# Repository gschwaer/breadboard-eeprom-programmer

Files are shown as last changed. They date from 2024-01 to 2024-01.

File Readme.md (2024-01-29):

# Breadboard EEPROM Programmer

> A parallel EEPROM programmer built on a breadboard.

The **SN74LV8153** is a serial-to-parallel IC. It can translate serial (yes, UART) to 8 parallel
output pins. In combination with a USB-to-serial converter this is a very powerful, yet simple setup
to interact with breadboard circuitry from a computer. We're going to leverage that for building an
EEPROM programmer.

No soldering required. No building firmware. No micro controller. Just assemble the circuit on a
breadboard, connect USB, and you're good to go!

## Hardware

We use three individually addressable SN74LV8153 chips. The one on the left (address 1) is used for
the 7 upper address lines (green) and the write enable signal (white). The one on the right
(address 0) is used for the 8 lower address lines (green). The last one (address 2) is used for the
8 data lines (blue). The serial data line (yellow) connects the TX output of the USB-to-serial
adapter (left) to the RX input of all SN74LV8153. And that's it. Plug the EEPROM in the middle and
get to flashing.

breadboard schematic

Color Coding:
- 🔴 5V
- ⚫ GND
- 🟢 Address Lines
- 🔵 Data Lines
- ⚪ IC Control
- 🟡 Serial

Here is the finished breadboard:

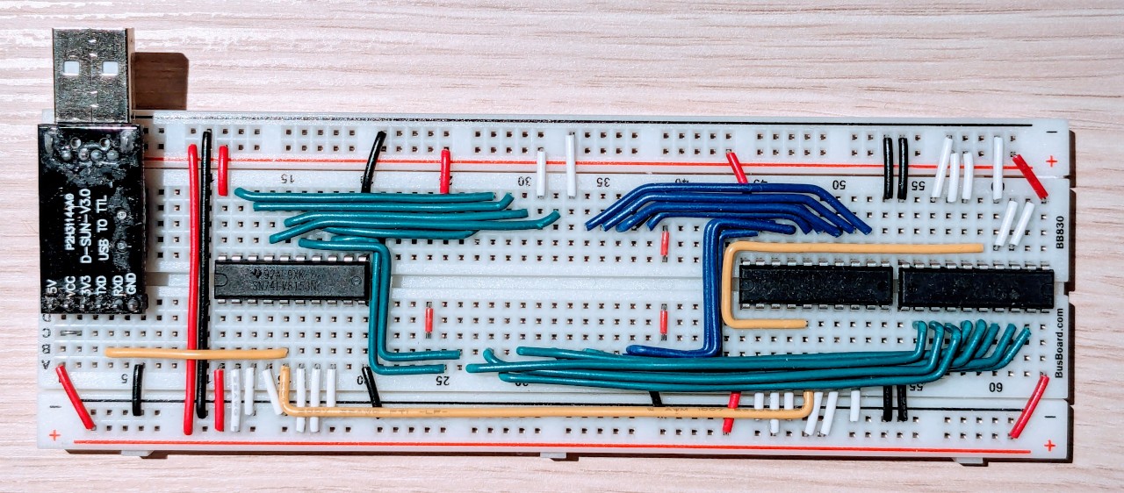
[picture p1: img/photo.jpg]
photo of breadboard


## Software

Written in python using `pyserial`. [Source Code.](bbeeprog.py)

### Setup

```bash
git clone https://github.com/gschwaer/breadboard-eeprom-programmer.git
cd breadboard-eeprom-programmer
python3.9 -m venv .venv
source .venv/bin/activate
pip install --upgrade pip wheel
pip install -r requirements.txt
```
Note: Should work fine with all python versions >= 3.8.

### Usage

Initialize the programmer (do this before inserting the EEPROM!)
```bash
./bbeeprog.py init /dev/ttyUSB0
```

Flash data to the EEPROM
```bash
./bbeeprog.py flash /dev/ttyUSB0 ~/my_file.hex
```

Flash only the data that changed between `~/my_old_file.hex` and `~/my_new_file.hex` to the EEPROM
```bash
./bbeeprog.py flash /dev/ttyUSB0 --only-changes=~/my_old_file.hex ~/my_new_file.hex
```
Warning: Beware, if the provided "old" file is not identical to the content of the EEPROM, the
         result is undefined.

The `--only-changes` option is especially useful when combined with a build script or a Makefile.
The flashing target can copy the binary to a hidden file after flashing and then provide the last
flashed binary on every new flashing. Something like so:
```Makefile
.PHONY: flash
flash: out.hex
ifeq ($(wildcard ./.out.hex),)
	$(bbeeprog) flash $(device) $<
else
	$(bbeeprog) flash --only-changes=.out.hex $(device) $<
endif
	cp out.hex .out.hex
```

## Pros And Cons

The Pros:

- 🧑‍🏭 No soldering needed
  - Circuit works purely on breadboard!
- 💻 No need to build firmware or flash a micro controller
  - It's basically hardware bit-banging with USB as data source!
- 🛒 Low cost
  - 7.62 € for 3x SN74LV8153 (each 2.54 € at Mouser in Jan 2024), the rest is components that you
    probably have laying around (Breadboard, USB-to-serial, and some jumper wires)!
- ✨ Flexible
  - So much possibilities! Some ideas: Need more address lines? Slap another SN74LV8153 on the
    breadboard. Want accurate timing? Trigger a 555 timer. Really want data back? Operate a USART
    like the Intel 8251 via a SN74LV8153.
- ♻️ No waste
  - Don't need it anymore? Disassemble and reuse the parts for some other project!

The Cons:
- 🙉 No input capabilities
  - We cannot read back the EEPROM content, so we cannot validate it either.
- ✋ Not suited for all EEPROMs
  - Built for AT28C256. Others: write cycle timing cannot be too demanding
    ([more](#more-on-limitations)).
- 🔨 Increased memory wear
  - Because of timing restraints, we cannot use the better page-write mode
    ([more](#more-on-limitations)).
- 🐌 Slow
  - Not blazingly fast, but usable for smaller EEPROMs. 32kB works fine.

## Docs

- [SN74LV8153](https://www.ti.com/lit/ds/symlink/sn74lv8153.pdf?ts=1706468538401) -
  Serial-to-parallel data converter
- [AT28C256](https://ww1.microchip.com/downloads/aemDocuments/documents/MPD/ProductDocuments/DataSheets/AT28C256-Industrial-Grade-256-Kbit-Paged-Parallel-EEPROM-Data-Sheet-DS2000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) - 32kB paged
  parallel EEPROM

## More On Limitations

**Timing:** This tool was written for the AT28C256. Others EEPROMs might work as well if they have
lax timing requirements similar to the AT28C256: Other EEPROMS sometimes require a maximum duration
for toggling of the write enable line. The AT28C256 does not have that for byte-wise writing. We
cannot accomplish tight upper bounded timing requirements, because serial via USB is just too slow
and has too much jitter.

**Wear:** We can only use byte-wise writing, because page-wise writing requires accurate timing on
the AT28C256. Instead, writing a page (64 bytes) is done by 64 single writes, that is 64 write
cycles, whereas page-wise writing would need only one cycle for 64 byte. Compared to a programmer
that supports page-wise writing, flashing the same amount of data is much slower and has increased
memory wear (more write cycles). Still, with the AT28C256's listed endurance, we can flash it over
150 times.

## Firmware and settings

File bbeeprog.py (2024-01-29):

"""
Program EEPROM with provided binary data.

Usage: bbeeprog.py init DEVICE
       bbeeprog.py flash [--only-changes=OLD_FILE] DEVICE FILE
       bbeeprog.py -h | --help

Arguments:
  DEVICE  path to the serial device
  FILE    binary input file

Options:
  -h --help                show this help
  --only-changes=OLD_FILE  flash only bytes that differ in FILE and OLD_FILE

Warning: Make sure to run `bbeeprog.py init` before inserting your EEPROM,
         otherwise the first byte may be overwritten to zero.
"""
from collections.abc import Iterable
import datetime
import itertools
import sys
import time

from docopt import docopt
import serial as pyserial  # type: ignore


class SN74LV8153:
    _serial: pyserial.Serial
    _addr: int
    _last_value: int

    MIN_BAUD_RATE = 2000
    MAX_BAUD_RATE = 24000

    def __init__(self, serial: pyserial.Serial, addr: int):
        assert SN74LV8153.MIN_BAUD_RATE <= serial.baudrate <= SN74LV8153.MAX_BAUD_RATE
        assert 0 <= addr < 8

        self._serial = serial
        self._addr = addr
        self._last_value = -1

    # Protocol layout:
    # Data byte is sent as two nibbles in two consecutive byte sized UART
    # telegrams (8N1, max 24k Baud).
    #
    # 1st Telegram:
    #   ,- regular UART start bit (by UART driver) (=0)
    #   |   ,- protocol start bit (in payload) (=1)
    #   |   |   ,- 3 address bits
    #   |   |   |              ,- 4 low data bits (low nibble)
    #   |   |   |              |                   ,- regular UART stop bit (by
    #   |   |   |              |                   |  UART driver) (=1)
    #   v   v   v              v                   v
    # .----------------------------------------------.
    # | 0 | 1 | A0 | A1 | A2 | D0 | D1 | D2 | D3 | 1 |
    # '----------------------------------------------'
    #     `- - - - - P A Y L O A D  - - - - - - -'
    # Note: UART sends lsb first, so D3 is bit 8.
    #
    # 2nd Telegram:
    # Identical to the first telegram, but contains the high nibble of data.
    # This telegram is required: If the second telegram is not received, the
    # first will be discarded.
    @staticmethod
    def _protocol(addr: int, value: int) -> bytes:
        low_nibble = (value & 0x0F) << 4 | addr << 1 | 1
        high_nibble = (value >> 4) << 4 | addr << 1 | 1

        return bytes([low_nibble, high_nibble])

    def write(self, value: int):
        value = value & 0xFF

        if value == self._last_value:
            # We don't use SOUT and performing this write would not change the
            # chip's output. Omitting the write will speed up EEPROM writing.
            return

        self._serial.write(SN74LV8153._protocol(self._addr, value))
        self._last_value = value


class BbEeProg:
    """Breadboard EEPROM Programmer"""

    _serial_port: str
    _serial: pyserial.Serial
    _addr_lo: SN74LV8153
    _addr_hi: SN74LV8153
    _data: SN74LV8153
    _dt_last_write: datetime.datetime

    # nWE: not Write Enable
    ADDR_HI_WRITE_DISABLE_BIT = 1 << 7
    # USB via UART is not very timing accurate, so we extend the 10ms rating by
    # a bit. On my T400, the smallest deviation I measured was -2.5ms, so double
    # that should be a solid default, I hope.
    WRITE_CYCLE_MS = 10 + 5

    def __init__(self, tty_dev: str):
        self._serial_port = tty_dev

    def __enter__(self):
        self._serial = pyserial.Serial(
            self._serial_port, baudrate=SN74LV8153.MAX_BAUD_RATE
        )

        self._addr_lo = SN74LV8153(self._serial, 0)
        self._addr_hi = SN74LV8153(self._serial, 1)
        self._data = SN74LV8153(self._serial, 2)

        # The SN74LV8153 starts with all output pins low. Write enable is active
        # low, so writing is enabled by default (not good). We initialize the
        # nWE pin to high during init, so the EEPROM should be inserted after
        # initialization, otherwise byte 0 might be overwritten with 0x00.
        self._addr_hi.write(BbEeProg.ADDR_HI_WRITE_DISABLE_BIT)

        # Setting this to `now()`, just in case the EEPROM was inserted before
        # initializing, so a write on byte 0 is in progress (see above). We
        # would get non-deterministic results in this case otherwise and the
        # tiny delay doesn't hurt on the happy path.
        self._dt_last_write = datetime.datetime.now()

        return self

    def __exit__(self, t, v, b):
        self._serial.close()

    def write_byte(self, addr: int, byte: int):
        assert addr <= 0x7FFF

        # There are some timing requirements in the <= 100 ns range for byte
        # writes on the AT28C256. They are all lower limits. We always satisfy
        # them, because the maximum baud rate slows us down into the micro
        # second range.

        self._data.write(byte)
        self._addr_lo.write(addr & 0xFF)
        # According to the AT28C256 data sheet, the address setup time before
        # nWE goes low is >= 0 ns. However, it also states that the address is
        # latched on the falling edge of nWE. If we would set up the address
        # lines together with pulling nWE low (below), capacitive signal delays
        # might ruin the write, so we set the address lines up in advance.
        self._addr_hi.write(addr >> 8 | BbEeProg.ADDR_HI_WRITE_DISABLE_BIT)

        delay = (
            (
                self._dt_last_write
                + datetime.timedelta(milliseconds=BbEeProg.WRITE_CYCLE_MS)
            )
            - datetime.datetime.now()
        ).total_seconds()
        if delay > 0:
            time.sleep(delay)

        # strobe write enable (nWE, active low)
        self._addr_hi.write(addr >> 8)
        self._addr_hi.write(addr >> 8 | BbEeProg.ADDR_HI_WRITE_DISABLE_BIT)
        self._dt_last_write = datetime.datetime.now()

    def write(self, data: Iterable[int], old_data: Iterable[int] = []):
        last_chunk_was_old = False
        last_chunk_start = 0
        for addr, (byte, old_byte) in enumerate(itertools.zip_longest(data, old_data)):
            assert addr < pow(2, 15), "Address overflow, too much data"

            if byte is None:  # old_data is larger than data
                break

            if byte == old_byte:
                if not last_chunk_was_old:
                    # start of old chunk
                    last_chunk_was_old = True
                    if addr != 0:
                        print(
                            f"{last_chunk_start:04x}...{addr - 1:04x}: Wrote "
                            f"{addr - last_chunk_start} byte"
                        )

                    last_chunk_start = addr

                continue
            else:
                if last_chunk_was_old:
                    # end of old chunk
                    last_chunk_was_old = False
                    print(
                        f"{last_chunk_start:04x}...{addr - 1:04x}: Skipped "
                        f"{addr - last_chunk_start} byte (no change)"
                    )
                    last_chunk_start = addr

                self.write_byte(addr, byte)

        if not last_chunk_was_old:
            print(
                f"{last_chunk_start:04x}...{addr:04x}: Wrote "
                f"{addr + 1 - last_chunk_start} byte"
            )
        else:
            if last_chunk_start == 0:
                print("Nothing to do (no changes)")
            else:
                print(
                    f"{last_chunk_start:04x}...{addr:04x}: Skipped "
                    f"{addr + 1 - last_chunk_start} byte (no change)"
                )

    def _file_read_bytes(self, file: str) -> Iterable[int]:
        with open(file, "r+b") as f:
            while True:
                data = f.read(1)
                if data == b"":
                    break

                yield data[0]

    def write_file(self, file: str):
        self.write(self._file_read_bytes(file))

    def write_file_diff(self, file: str, diff_file: str):
        self.write(self._file_read_bytes(file), self._file_read_bytes(diff_file))


if __name__ == "__main__":
    arguments = docopt(__doc__)

    with BbEeProg(arguments["DEVICE"]) as bbeeprog:
        if arguments["init"]:
            # programmer was initialized in EEProg.__init__()
            print("Initialized. Ready for EEPROM insertion.")
            sys.exit(0)

        if arguments["flash"]:
            ts_start = time.time()
            if arguments["--only-changes"]:
                print("Note: Flashing in changes only mode.")
                bbeeprog.write_file_diff(arguments["FILE"], arguments["--only-changes"])
            else:
                bbeeprog.write_file(arguments["FILE"])

            ts_end = time.time()
            print(f"Writing took {round(ts_end-ts_start, 3)}s.")

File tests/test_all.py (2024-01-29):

import pytest

from bbeeprog import SN74LV8153, BbEeProg
import serial as pyserial  # type: ignore


def test_protocol():
    buffer = SN74LV8153._protocol(5, 0xAB)
    assert len(buffer) == 2
    assert buffer[0] == 0xBB
    assert buffer[1] == 0xAB


@pytest.mark.skip(reason="manual")
def test_hardware():
    """Output test without EEPROM

    Using a signal analyzer we can check if we wired everything correctly.

    This test should put all values from 0-255 onto all chips' outputs.

    Note: Assumes the device is detected as `/dev/ttyUSB0`.
    """
    serial = pyserial.Serial("/dev/ttyUSB0", baudrate=24000)
    addr_lo = SN74LV8153(serial, 0)
    addr_hi = SN74LV8153(serial, 1)
    data = SN74LV8153(serial, 2)

    for n in range(256):
        addr_lo.write(n)
        addr_hi.write(n)
        data.write(n)


@pytest.mark.skip(reason="manual")
def test_eeprom_content_write():
    """Fill the EEPROM with known data

    Write 32k with byte values from 0 to 255 (repeating), but clamp the lowest
    number to the number of completed repetitions, e.g.:
    ```
    0,1,2,3, ... 255  # byte   0 to 255
    1,1,2,3, ... 255  # byte 256 to 511
    2,1,2,3, ... 255  # byte 512 to 767
    ```
    and so forth.

    Read back with test below.

    Note: Assumes the device is detected as `/dev/ttyUSB0`.
    """
    bbeeprog = BbEeProg("/dev/ttyUSB0")
    values = (max(n % 256, int(n / 256)) for n in range(pow(2, 15)))
    bbeeprog.write(values)


@pytest.mark.skip(reason="manual")
def test_eeprom_content_read():
    """Read back data (with signal analyzer)

    Read 32k bytes from EEPROM. We cannot really read anything using the
    SN74LV8153, so we have to sample the data lines with a signal analyzer and
    manually analyze the result.

    It's easiest to connect the signal analyzer to the pins of the SN74LV8153.

    Using a signal analyzer we can read the content: Pull the nOE of the data
    SN74LV8153 high (disable) and the nOE of the EEPROM low (enable).

    Note: Assumes the device is detected as `/dev/ttyUSB0`.
    """
    serial = pyserial.Serial("/dev/ttyUSB0", baudrate=24000)
    addr_lo = SN74LV8153(serial, 0)
    addr_hi = SN74LV8153(serial, 1)

    for addr in range(pow(2, 15)):
        addr_lo.write(addr & 0xFF)
        addr_hi.write(addr >> 8 | BbEeProg.WRITE_DISABLE_BIT)


@pytest.mark.skip(reason="manual")
def test_timing():
    """Ensure write timing

    Verifying that we don't write too fast:
    Using a signal analyzer and PulseView we can measure the timing of the nWE
    signal and export it as csv. The report will contain the duration of nWE
    being low and high in micro seconds.

    Protocol decoder "Timing" setup:
    - Format of 'time' annotation: terse-us
    - Averaging period: 0 (disables averaging)
    - Edges to check: any
    New View: Tabular Decoder Output View
    - Export as csv
    """
    import csv

    with open("write_enable_timing.csv", "r", newline="") as f:
        # quick and dirty csv read
        r = csv.reader(f, delimiter=",", quotechar='"')
        r.__next__()  # skip header
        data = []
        for row in r:
            assert len(row) == 7
            assert row[2] == "Timing"
            data.append(int(row[5]))

        # ensure write enable is low >= 10 ms
        nwe_high_us = 3 * 1000  # arbitrary, makes detecting writes easier
        nwe_low_us = 12 * 1000

        min_nwe_low = 9999999999
        max_nwe_high = 0

        for i in range(len(data) - 3 + 1):
            print(data[i : i + 3])
            assert data[i] <= nwe_high_us or data[i] >= nwe_low_us
            if data[i] <= nwe_high_us:
                assert data[i + 1] >= nwe_low_us
                assert data[i + 2] <= nwe_high_us
                min_nwe_low = min(min_nwe_low, data[i + 1])
                max_nwe_high = max(max_nwe_high, max(data[i], data[i + 2]))

        # compare with permitted values in data sheet
        print(f"Min nWE low = {min_nwe_low} us")
        print(f"Max nWE high = {max_nwe_high} us")
